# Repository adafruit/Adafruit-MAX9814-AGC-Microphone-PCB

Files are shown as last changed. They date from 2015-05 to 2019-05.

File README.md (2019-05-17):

# Adafruit MAX9814 AGC Microphone PCB
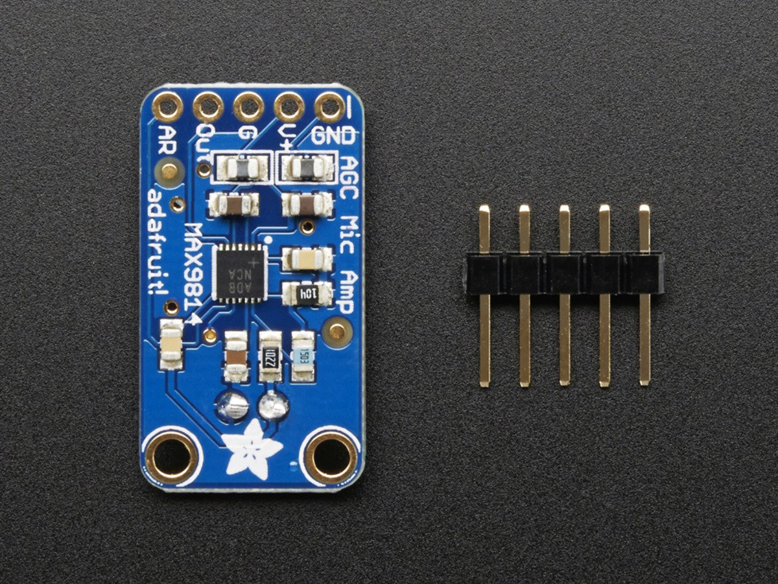
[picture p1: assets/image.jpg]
<a href="http://www.adafruit.com/products/1713"><br/>
Click here to purchase one from the Adafruit shop</a>

Add an ear to your project with this well-designed electret microphone amplifier with AGC. This fully assembled and tested board comes with a 20-20KHz electret microphone soldered on. For the amplification, we use the Maxim MAX9814, a specialty chip that is designed for amplifying electret microphones in situations where the loudness of the audio isn't predictable.

The chip at the heart of this amp is the MAX9814, and has a few options you can configure with the breakout. The default 'max gain' is 60dB, but can be set to 40dB or 50dB by jumpering the Gain pin to VCC or ground. You can also change the Attack/Release ratio, from the default 1:4000 to 1:2000 or 1:500. The ouput from the amp is about 2Vpp max on a 1.25V DC bias, so it can be easily used with any Analog/Digital converter that is up to 3.3V input. If you want to pipe it into a Line Input, just use a 1-100uF blocking capacitor in series (100uF sounds best).

PCB files for MAX9814 AGC Microphone. The format is EagleCAD schematic and board layout

- https://www.adafruit.com/product/1713

### License

Adafruit invests time and resources providing this open source design, please support Adafruit and open-source hardware by purchasing products from [Adafruit](https://www.adafruit.com)!

All text above must be included in any redistribution

Designed by Limor Fried/Ladyada for Adafruit Industries.
Creative Commons Attribution/Share-Alike, all text above must be included in any redistribution. 
See license.txt for additional information.

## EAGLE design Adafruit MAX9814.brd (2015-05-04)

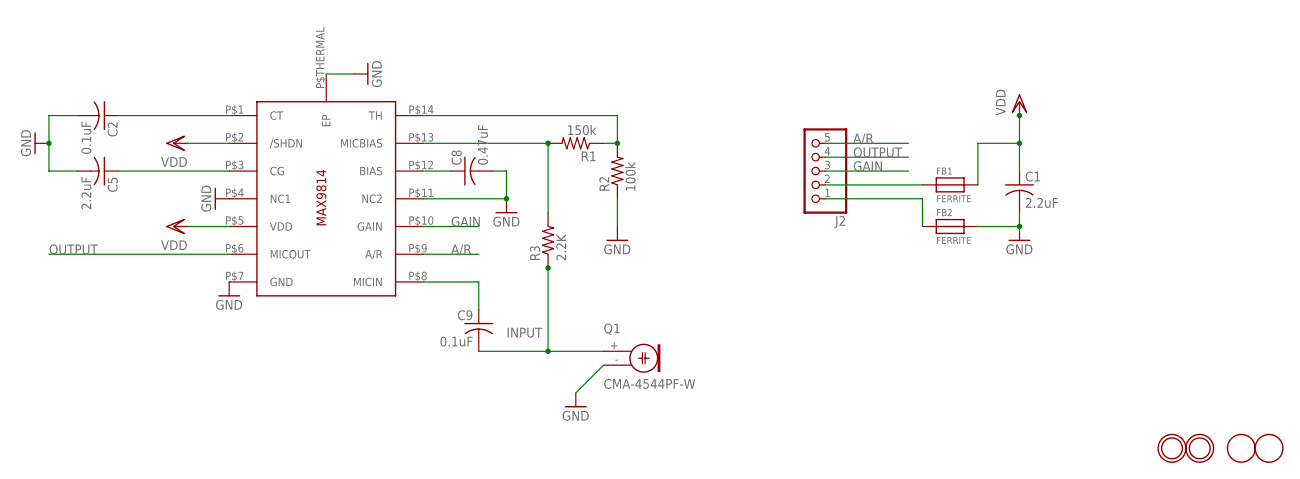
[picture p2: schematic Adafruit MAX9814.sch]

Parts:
C1, C5: 2.2uF; C0805K
C2, C9: 0.1uF; C0805K
C8: 0.47uF; C0805K
FB1, FB2: FERRITE; 0805
J2: HEADER-1X576MIL; 1X05_ROUND_76
Q1: CMA-4544PF-W; 9.7ELECTRET
R1: 150k; R0805
R2: 100k; R0805
R3: 2.2K; R0805
U$1: MAX9814TDFN14; TDFN14_3X3MM
U$2, U$3: FIDUCIAL; FIDUCIAL_1MM
U$4, U$5: MOUNTINGHOLE2.0; MOUNTINGHOLE_2.0_PLATED

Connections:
A/R: J2.5, U$1.P$9 (A/R)
GAIN: J2.3, U$1.P$10 (GAIN)
GND: C1.2, C2.2, C5.2, C8.2, FB2.2, Q1.- (1), R2.1, U$1.P$4 (NC1), U$1.P$7 (GND), U$1.P$11 (NC2), U$1.P$THERMAL (EP)
INPUT: C9.2, Q1.+ (2), R3.1
unnamed: FB1.1, J2.2
unnamed: FB2.1, J2.1
unnamed: C9.1, U$1.P$8 (MICIN)
unnamed: C8.1, U$1.P$12 (BIAS)
unnamed: C2.1, U$1.P$1 (CT)
unnamed: C5.1, U$1.P$3 (CG)
unnamed: R1.1, R2.2, U$1.P$14 (TH)
unnamed: R1.2, R3.2, U$1.P$13 (MICBIAS)
OUTPUT: J2.4, U$1.P$6 (MICOUT)
VDD: C1.1, FB1.2, U$1.P$2 (/SHDN), U$1.P$5 (VDD)

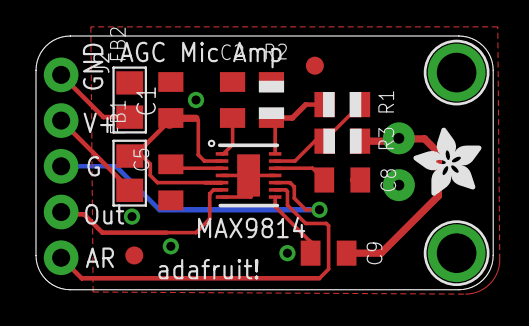
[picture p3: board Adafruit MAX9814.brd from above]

Board: 2 copper layers, 25.4 x 14.1 mm, 18 parts (1 on the bottom side), 14 nets.

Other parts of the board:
U$6: ADAFRUIT_3.5MM
